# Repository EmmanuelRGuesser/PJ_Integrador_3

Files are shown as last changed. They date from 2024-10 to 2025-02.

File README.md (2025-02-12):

---
CI

# Medidor de consumo elétrico residencial com ESP32
---

Este projeto tem como objetivo realizar o projeto e implementação de um dispositivo de monitoramento do consumo energético de tomadas residenciais integrado ao Home Assistant.

Dispositivos como esse permitem aos usuários monitorar e controlar o consumo de energia, ajudando a identificar aparelhos que consomem muita energia e incentivar hábitos mais sustentáveis. Isso resulta em uma redução significativa na fatura de energia e contribui para a conservação de recursos naturais.

Com o aumento das tarifas de energia elétrica, ser capaz de identificar os maiores consumidores de energia em casa pode gerar economia substancial. Um dispositivo que fornece dados detalhados permite aos consumidores tomar decisões informadas para reduzir o consumo e, consequentemente, os custos.

## Funcionalidades:

- Integração com o Home Assistant;
- Monitoramento da tensão, corrente, potência, frequência e fator de potência;
- Visualiazação do histórico de consumo;
- Sistema de acionamento a distância;
- Sistema de proteção do dispositivo.  

## Dispositivo

O dispositivo funcionará entre as tomadas adquirindo os dados por meio do sensor PZEM-004T, abaixo temos uma representação dele:

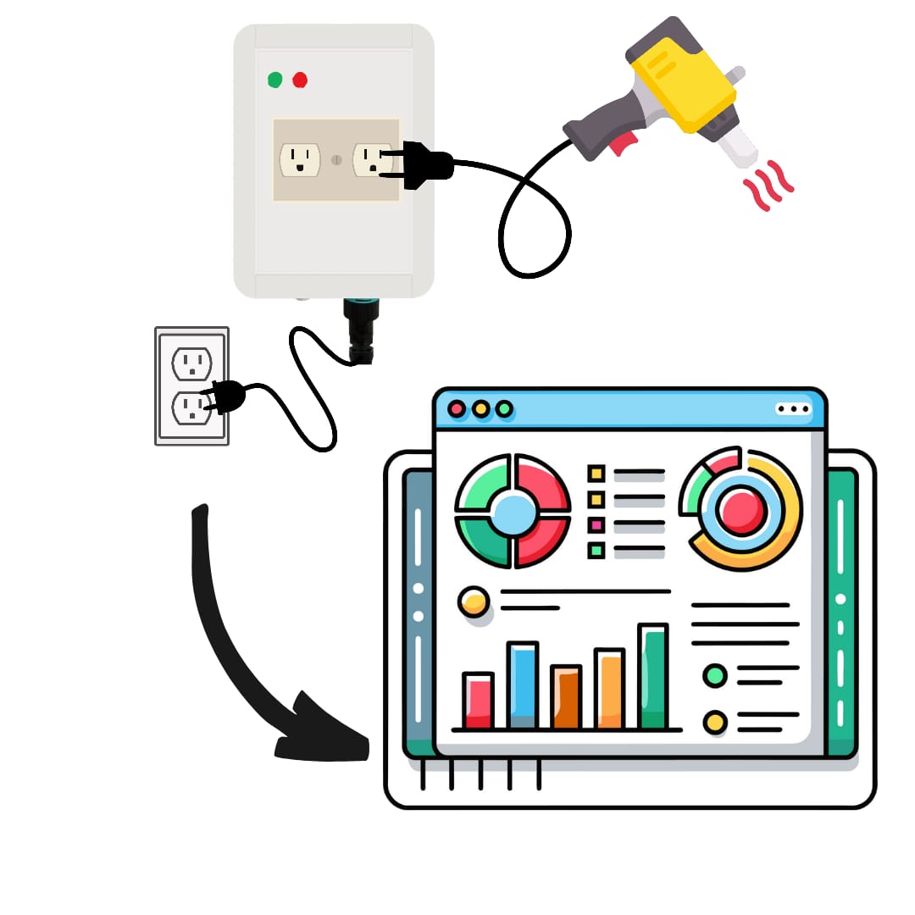
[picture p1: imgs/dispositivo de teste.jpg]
dispositivo


Ele deve ser conectado a tomada para o fornecimento de energia, dentro da case possui uma fonte para alimentar o ciruito. Esse circuito é composto pelo microcontrolador(ESP32), sensor(PZEM-004t), relé de acionamento e leds para fácil identificação do funcionamento, já a interface será integrada com o Home Assistant.

Para o projeto será utilizado os seguintes componentes:
- ESP32
- PZEM-004t
- Relé
- Fonte Hi-link 5V 3W
- 2 leds
- Display LCD 20x4
- Case takachi WPL15-15-6

---
## Descrição dos componentes

### ESP32
O ESP32 é um microcontrolador de baixo custo e baixa potência, desenvolvido pela Espressif Systems. Ele integra Wi-Fi e Bluetooth, tornando-se uma escolha popular para projetos de Internet das Coisas (IoT), além disso a comunidade em torno do ESP32 é enorme, com muitos recursos, bibliotecas e tutoriais disponíveis. A Espressif, empresa desenvolvedora, também oferece um SDK robusto (ESP-IDF). 

### PZEM-004t
O PZEM-004T é um módulo que possui funcionalidades de Voltimetro, Amperímetro e Wattimetro. Os dados são transmitidos para o microcontrolador por meio de comunicação serial TTL. 

### Fonte Hi-link 5V
É um conversor step down que trabalha com uma tensão de alimentação AC-DC 127/220V para 5V, com uma potencia de 5W, o qual será suficiente para alimentar o microcontrolador e os periféricos contidos no circuito. Foi escolhido esse modelo de fonte pois é compacta, facil de encontrar no mercado e possui certificações que garantem a qualidade da tensão e corrente entregues na saída, dentro da potencia especificada.

### LEDs
O dispositivo conta com dois leds que dão um feedback do funcionamento do sistema. Um led vermelho indicará que o circuito está ligado e outro led verde indicará estado de conexão com o wifi.

---
## Home Assistant

O Home Assistant é uma plataforma de automação residencial de código aberto que permite controlar dispositivos e sistemas em sua casa de maneira centralizada e automatizada. Ele suporta uma ampla variedade de dispositivos e protocolos, facilitando a criação de cenários de automação e controle de tudo, desde luzes e termostatos até câmeras de segurança e sistemas de entretenimento.

#### Principais características do Home Assistant:
- Automação: Criação de regras de automação personalizadas com base em eventos, horários ou condições específicas.
- Integrações: Suporte a milhares de dispositivos e serviços, como Philips Hue, Google Assistant, Amazon Alexa, entre muitos outros.
- Controle Local: Embora possa ser integrado à nuvem, o Home Assistant é projetado para funcionar localmente, o que oferece maior privacidade e controle.
- Dashboard Personalizado: A plataforma oferece uma interface visual personalizável para que você possa monitorar e controlar dispositivos.

#### Integração com ESP32 no Home Assistant
O ESP32 é um microcontrolador com conectividade Wi-Fi e Bluetooth, amplamente utilizado em projetos de automação e IoT (Internet das Coisas). No contexto do Home Assistant, o ESP32 é frequentemente usado para criar dispositivos personalizados, como sensores e atuadores. A integração entre o ESP32 e o Home Assistant ocorre principalmente por meio do protocolo MQTT Moskitto.

Funcionamento da Integração:

1. Configurar a rede Wi-Fi e login do Home Assistant na pagina WEB gerada pelo ESP.
2. O Home Assistant recebe os dados por meio do protocolo MQTT Moskito.
3. Armazena os dados em forma de entidades, no bando de dados InfluxDB.
4. No banco de dados possui um dashboard o qual mostra todos os dados plotados para o gerenciamento.

---

## Funcionamento do Monitor de Energia

Para o funcionamento do dispositivo devemos conectar a rede Wi-FI, isso é feito através do aplicativo ESP BLE Provising que está disponível na Play Store e App Store, leia o [código QR do link](https://espressif.github.io/esp-jumpstart/qrcode.html?data=%7B%22ver%22:%22v1%22,%22name%22:%22Monitor%20de%20energia%22,%22pop%22:%22abcd1234%22,%22transport%22:%22ble%22%7D) ou procure por monitor de energia e use a senha “abc1234”, com isso você pode ver as redes disponíveis e fazer a conexão, caso necessário reconfigurar a rede, somente pressione o botão ao lado da entrada de alimentação por 3 segundos que seu dispositivo irá reiniciar e basta seguir os passos anteriores. 

Agora é possível acessar a página de configurações através do Web Server gerado pela ESP32, acesse [monitor-energia.local](http://monitor-energia.local/), através dela você deve configurar o serviço MQTT para realizar a comunicação de dados entre o monitor de energia e o Home Assistant, use sua conta e senha do seu perfil do HA. Você também pode configurar os alertas, visualizar o consumo acumulado, além de ligar e desligar o dispositivo conectado através da página.

O sistema de alertas funciona como uma proteção que irá atuar desligando o dispositivo conectado ao monitor, a proteção age sobre tensão mínima e tensão, corrente e potência máxima, sempre que um alerta é disparado um aviso é exibido na tela, para voltar ao funcionamento basta clicar no botão ligar. Caso você queira não utilizar os alertas, somente deixe o item com 0. 
Na página de consumo acumulado é exibido quantidade de energia consumida pelo dispositivo conectado, com isso você pode estimar o valor gasto com ele, caso você queira trocar o dispositivo monitorado ou no que for necessário, você pode zerar o contador clicando em zerar energia.

Com isso, já é possível ver na tela LCD do monitor dados como tensão, corrente, potência e energia consumida, além dos avisos do dispositivos e informaçãoes já descritas acima, isso sem a necessidade de integrar com o Home Assistant , porém para conseguir monitorar os dados ao decorrer do tempo em um gráfico, você deve seguir os passos abaixo.

---
### Instalação do Home Assistant
Como o Home Assistant funciona localmente é necessário fazer a instalação em um computador, máquina virtual ou um Raspberry Pi por exemplo. 

Para acessar o processo de instalação [click aqui](https://www.home-assistant.io/installation/).

Com o Home Assistant instalado vamos adicionar o Moskitto MQTT

---
### Guia para Adicionar MQTT Mosquitto no Home Assistant
Instalar o Add-on:

Acesse Configurações → Add-ons, Backup & Supervisor
Vá em Loja de Add-ons e instale o Mosquitto broker
Configurar o Mosquitto:

No add-on, clique em Configuração e edite conforme necessário
Se precisar de autenticação, crie usuários em Configurações → Pessoas e Acesso
Habilitar e Iniciar:

Ative Iniciar na inicialização e Assistente de Rede
Clique em Iniciar
Verificar Funcionamento:

Vá em Configurações → Dispositivos e Serviços
Adicione uma integração MQTT, com isso no menu de configurações já deve ser possível se inscrever em algum tópico para receber os pacotes via MQTT.
No momento têm-se o tópico *sensor* e os sub tópicos *voltage, current, power, energy, frequency e pf*, para ver a tensão por exemplo, deve-se se inscrever no *sensor/voltage*, como resultado você deve ver algumo semelhante a isto:

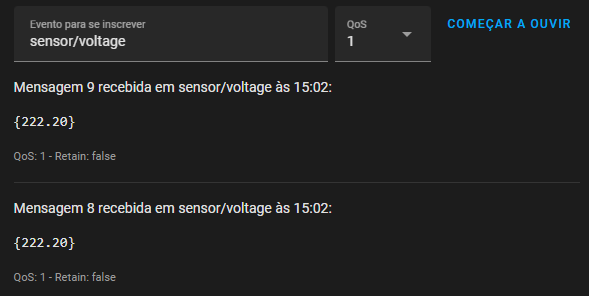
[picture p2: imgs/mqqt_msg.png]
mqtt_msg
 

Para salvar os dados será utilizado o File editor para criar as entidades que serão atribuidas aos dados que são recebidos via mqtt.

Com o File Editor aditaremos o arquivo */homeassistant/configuration.yaml*, basta adicionar o seguinte código para criar as entidades:
```
mqtt:    
    sensor:
        - name: voltage
          state_topic: "sensor/voltage"
          unit_of_measurement: V

        - name: current
          state_topic: "sensor/current"
          unit_of_measurement: A

        - name: power
          state_topic: "sensor/power"
          unit_of_measurement: W

        - name: energy
          state_topic: "sensor/energy"
          unit_of_measurement: Wh

        - name: frequency
          state_topic: "sensor/frequency"
          unit_of_measurement: Hz
          
        - name: fp
          state_topic: "sensor/pf"
          unit_of_measurement: fp
```
Agora vamos criar o banco de dados com o InfluxDB, para armazenar os dados e os manipular.

---
### Adicionando o InfluxDB no Home Assistant
Instalar o Add-on:

Acesse Configurações → Add-ons, Backup & Supervisor
Instale o InfluxDB
Criar um Banco de Dados e Usuário:

No terminal do InfluxDB, execute:
```
CREATE DATABASE home_assistant;
CREATE USER ha_user WITH PASSWORD 'senha' WITH ALL PRIVILEGES;
```
(Opcional) Restringir permissões:
```
GRANT ALL ON home_assistant TO ha_user;
```
Configurar no Home Assistant:
Adicione no configuration.yaml:
```
influxdb:
  host: a0d7b954-influxdb
  port: 8086
  database: home_assistant
  username: ha_user
  password: senha
  max_retries: 3
  default_measurement: state
```
Reinicie o Home Assistant

Para Verificar Funcionamento:

Acesse Desenvolvedor → Ferramentas de Estado para ver os dados sendo enviados

Pronto! Agora o MQTT e o InfluxDB estão integrados ao Home Assistant. 🚀

---
### Gerar o Dashboard e os gráficos no InfluxDB
1. Acessar o InfluxDB
2. No Home Assistant, vá para Configurações → Add-ons, Backup & Supervisor
Abra o InfluxDB e clique em Abrir Web UI
3. Criar um Dashboard
No menu lateral, vá em Dashboards
Clique em + Create Dashboard
Dê um nome ao dashboard e clique em Create
4. Criar um Gráfico
No dashboard criado, clique em + Create Cell
Escolha o tipo de visualização (Linha, Barras, Gauge, etc.)
Selecione Configure Query e escolha o banco de dados home_assistant
5. Construir a Query
   
OBS: O código das query estão no arquivo [Código_dos_gráficos_influxDB.md](https://github.com/EmmanuelRGuesser/PJ_Integrador_3/blob/main/C%C3%B3digo_dos_gr%C3%A1ficos_influxDB.md)

6. Utilizando os códigos, você pode personalizar os gráficos como desejar.

---

### Teste do Monitor de Energia

Para o teste vamos monitorar o carregamento de um notebook, após realizar as configuração de conexão do monitor e do Home Assistant conforme o passo a passo acima, podemos monitorar o consumo através da tela LCD no monitor ou pelo dashboard no Home Assistant.

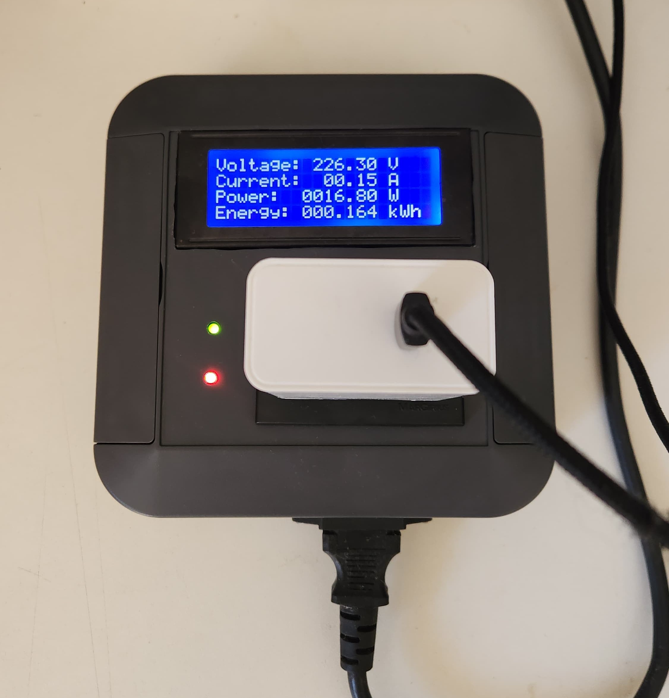
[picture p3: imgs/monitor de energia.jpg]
monitor
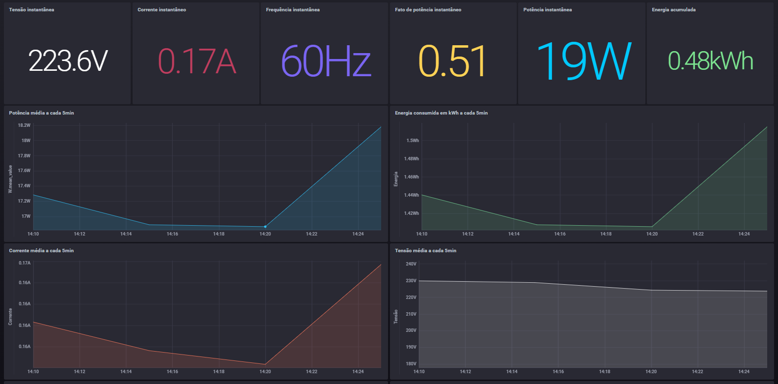
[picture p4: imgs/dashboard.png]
dashboard
  

Como visto acima podemos monitorar os parâmetros elétricos do dispositivo conectado ao monitor. Vamos testar o sistema de proteção, como a potência consumida é entre 15W - 20 W então para provocar um alerta iremos limitar em 10W, para isso entramos no página web do monitor de energia → configurar alertas e colocamos Max Power com 10W.

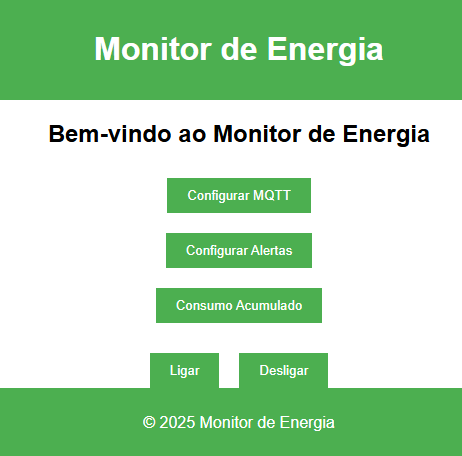
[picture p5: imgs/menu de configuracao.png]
tela principal
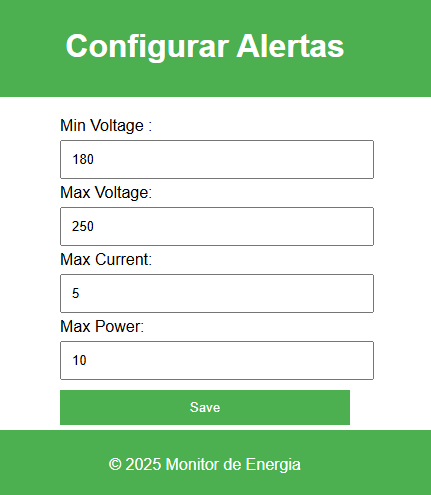
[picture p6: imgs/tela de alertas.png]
tela de alertas
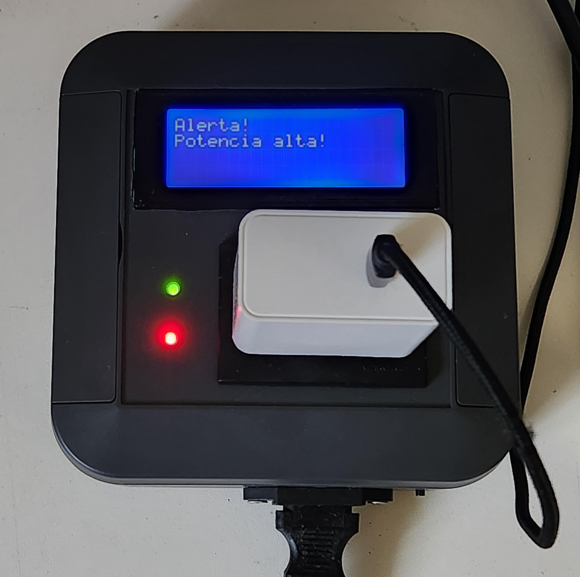
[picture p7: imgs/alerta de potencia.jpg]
alerta de potencia
  

Como vemos acima o monitor entra em modo proteção e desliga a carga, para voltar a funcionar é necessário ligar novamente no menu principal.

O consumo acumulado pode ser acessado pelo menu e la você poderá estimar o valor gasto pela caraga conectada, somente digite o valor pago por kWh e calcule. Caso você quiser zerar o contador nesta página também é possível fazer isto.

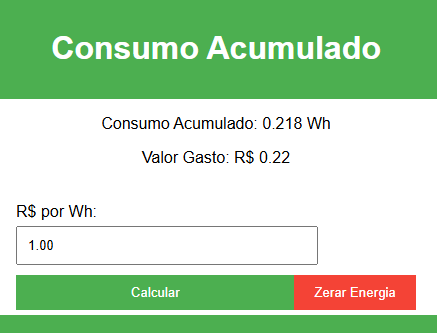
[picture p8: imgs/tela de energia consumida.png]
tela energia consumida


---

## Considerações finais

O desenvolvimento do projeto atingiu seus objetivos propostos, resultando em um dispositivo funcional capaz de monitorar o consumo elétrico de forma eficiente. A integração do hardware e software permitiu a coleta e visualização dos dados em tempo real, proporcionando um produto prático para automação residencial. Para projetos futuros, considera-se a possibilidade de utilizar um banco de dados mais robusto, um software mais avançado para a criação do dashboard e a adoção de componentes SMD para um design mais compacto, eficiente e profissional, reduzindo o tamanho da case e aprimorando a estética e usabilidade do dispositivo.

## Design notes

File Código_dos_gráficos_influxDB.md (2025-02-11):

---
#### Este arquivo contem os códigos referente aos gráficos gerados no dashboard dentro do InfluxDB.
## Valores instantâneos:

#### Tensão:
```
SELECT last("value") AS "instant_voltage"
FROM "sensor"."autogen"."V"
WHERE time > :dashboardTime: AND time < :upperDashboardTime:
```
#### Corrente:
```
SELECT last("value") AS "instant_value"
FROM "sensor"."autogen"."A"
WHERE time > :dashboardTime: AND time < :upperDashboardTime:
```
#### Frequencia:
```
SELECT last("value") AS "frequencia"
FROM "sensor"."autogen"."Hz"
WHERE time > :dashboardTime: AND time < :upperDashboardTime:
```
#### Fator de potencia:
```
SELECT last("value") AS "fatordepotencia"
FROM "sensor"."autogen"."fp"
WHERE time > :dashboardTime: AND time < :upperDashboardTime:
```
#### Potencia:
```
SELECT last("value") AS "instant_power"
FROM "sensor"."autogen"."W"
WHERE time > :dashboardTime: AND time < :upperDashboardTime:
```
#### Energia:
```
SELECT last("value") AS "instant_energy"
FROM "sensor"."autogen"."Wh"
WHERE time > :dashboardTime: AND time < :upperDashboardTime:
```
## Valores média de 5min:

#### Tensão média:
```
SELECT mean("value") AS "mean_voltage"
FROM "sensor"."autogen"."V"
WHERE time > :dashboardTime: AND time < :upperDashboardTime:
GROUP BY time(5m) FILL(null)
```
#### Corrente média:
```
SELECT mean("value") AS "Corrente média"
FROM "sensor"."autogen"."A"
WHERE time > :dashboardTime: AND time < :upperDashboardTime:
GROUP BY time(5m) FILL(null)
```
#### Frequencia média:
```
SELECT mean("value") AS "Frequencia"
FROM "sensor"."autogen"."Hz"
WHERE time > :dashboardTime: AND time < :upperDashboardTime:
GROUP BY time(5m) FILL(null)
```
#### Fator de potencia média:
```
SELECT mean("value") AS "PF"
FROM "sensor"."autogen"."fp"
WHERE time > :dashboardTime: AND time < :upperDashboardTime:
GROUP BY time(5m) 
FILL(null)

```
#### Potencia média:
```
SELECT mean("value") AS "mean_value"
FROM "sensor"."autogen"."W"
WHERE time > :dashboardTime: AND time < :upperDashboardTime:
GROUP BY time(5m) FILL(null)
```
#### Energia média:
```
SELECT mean("value") * (5/60) AS "energy_Wh" 
FROM "sensor"."autogen"."W" 
WHERE time > :dashboardTime: AND time < :upperDashboardTime: 
GROUP BY time(5m) FILL(null)
```
## Valor total por dia da última semana:

#### Potencia total do dia na ultima semana:
```
SELECT sum("value") AS "Potencia total"
FROM "sensor"."autogen"."W"
WHERE time >= now() - 7d AND time < now()
GROUP BY time(1d) FILL(null)
```
#### Energia tota do dia na ultima semana:
```
SELECT sum(energy_Wh) AS "daily_energy_Wh" 
FROM (
    SELECT mean("value") * (5/60) AS energy_Wh 
    FROM "sensor"."autogen"."W" 
    WHERE time > now() - 7d 
    GROUP BY time(5m) 
    FILL(null)
) 
GROUP BY time(1d) 
FILL(null)
```

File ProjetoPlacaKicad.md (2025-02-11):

---
#### Projeto da placa
---

Foi utilizado o Kicad 8.0 para realizar o projeto do esquemático e layout da placa, o modelo 3D tambem.

Na imagem abaixo, verifica-se o esquemático, contendo as ligações da alimentação utilizando uma fonte Hi-link 5V e 5W, circuito para reset da carga utilizando um acionamento de relé, sensor PZEN-004T com comunicação serial, os leds indicativos de alimentação e conexão com WiFi e o display LCD que utiliza o protocolo I2C.
CI

Na imagem abaixo podemos verificar o layout da placa, foi utilizado uma PCI de única face com dimensões de 10x8cm
CI

Na imagem abaixo podemos verificar o modelo 3D.
CI

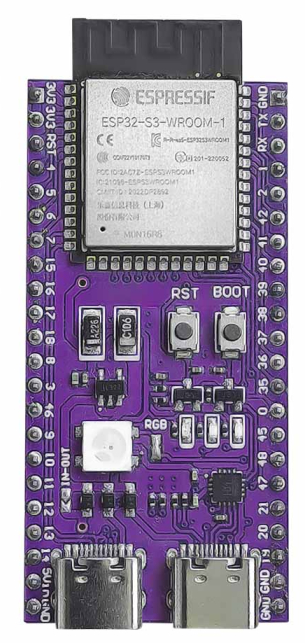
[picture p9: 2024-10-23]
imgs/esp32.png

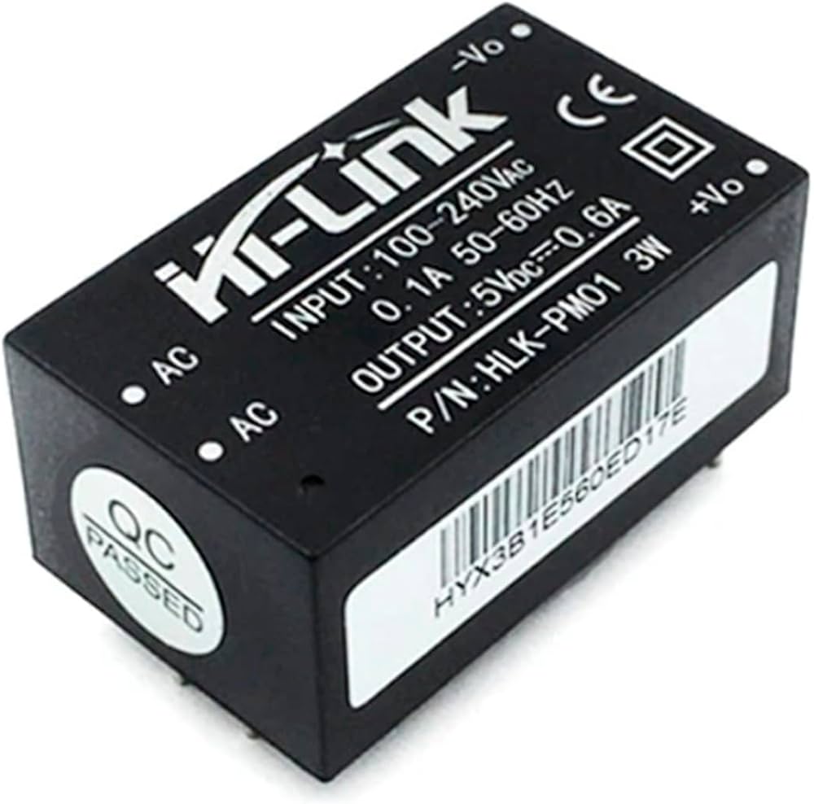
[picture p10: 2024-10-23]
imgs/fonte.jpg

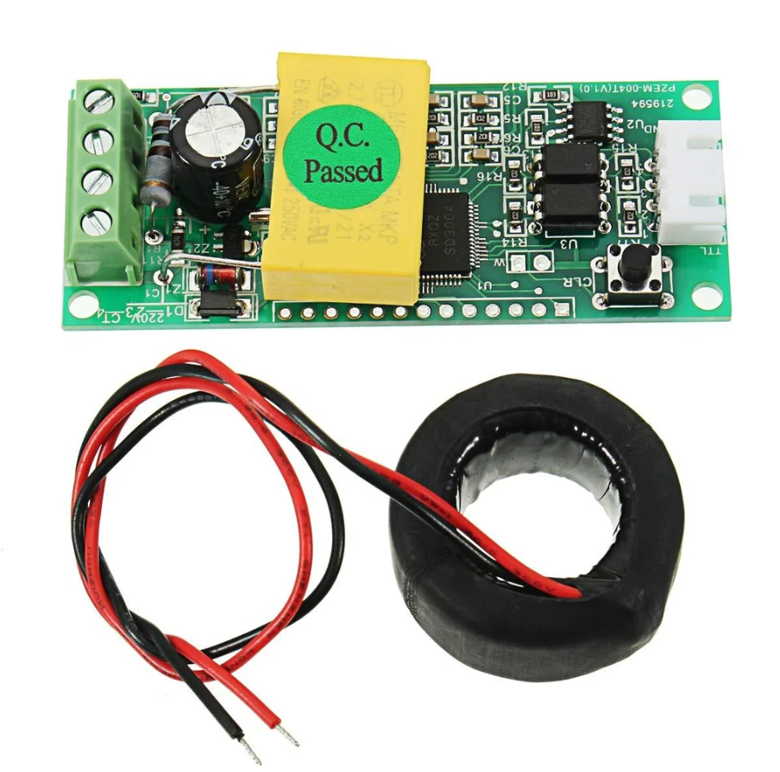
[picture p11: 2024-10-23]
imgs/pzem-004.png

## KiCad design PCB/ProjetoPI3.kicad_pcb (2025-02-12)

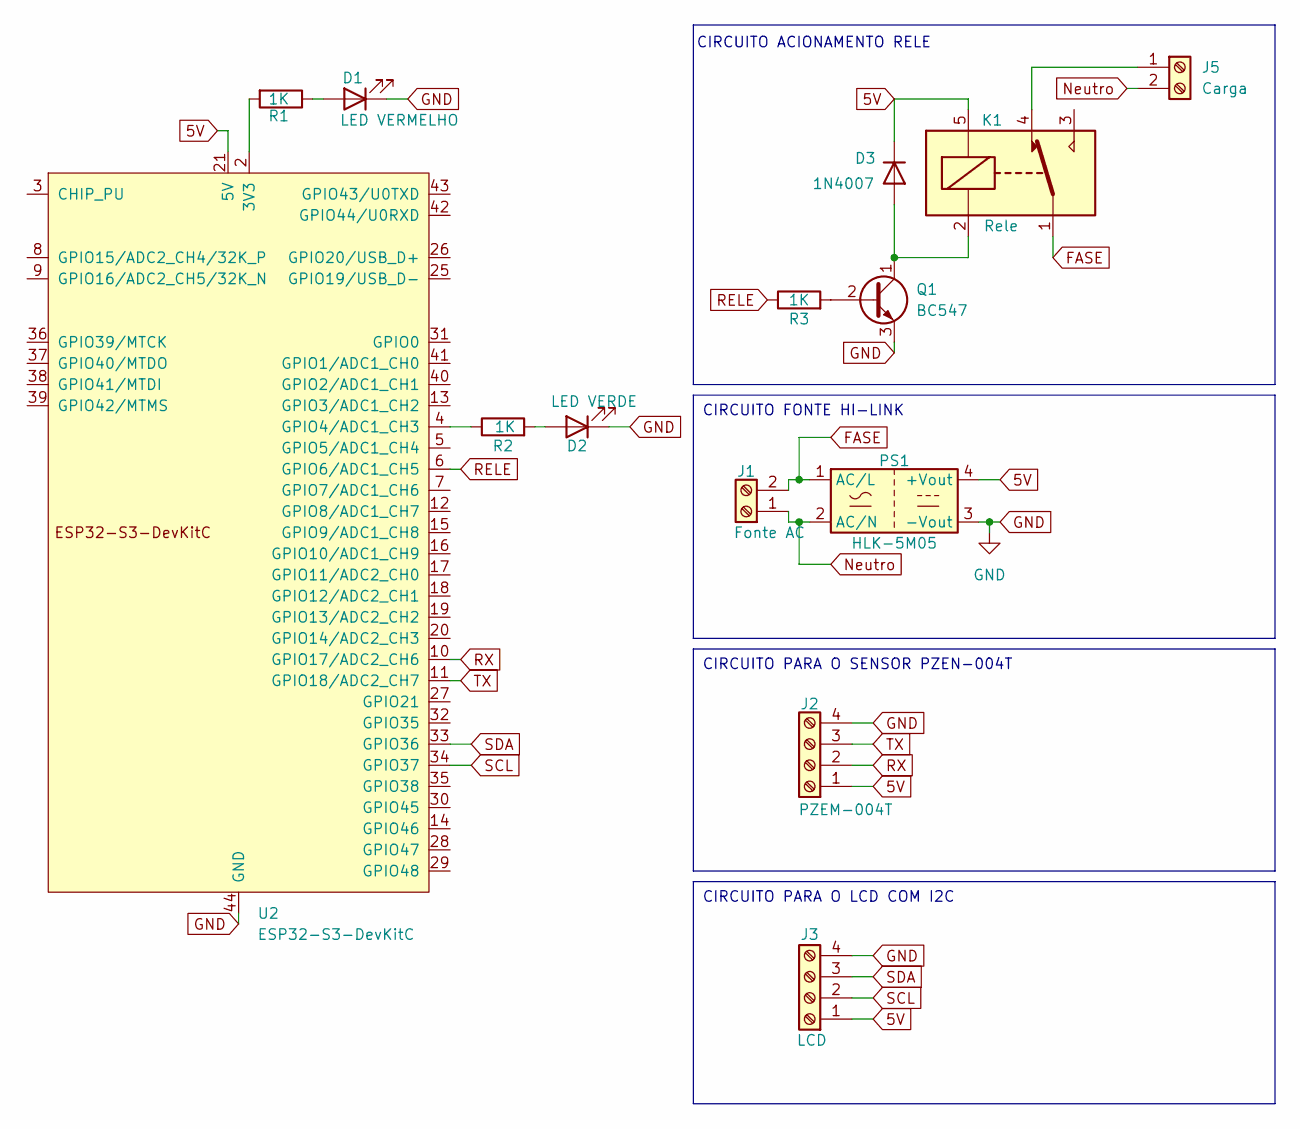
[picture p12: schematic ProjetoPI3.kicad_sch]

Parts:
D1: LED VERMELHO; TerminalBlock_Altech_AK300-2_P5.00mm
D2: LED VERDE; TerminalBlock_Altech_AK300-2_P5.00mm
D3: 1N4007; D_DO-41_SOD81_P10.16mm_Horizontal
J1: Fonte AC; TerminalBlock_Altech_AK300-2_P5.00mm
J2: PZEM-004T; TerminalBlock_Altech_AK300-4_P5.00mm
J3: LCD; TerminalBlock_Altech_AK300-4_P5.00mm
J5: Carga; TerminalBlock_Altech_AK300-2_P5.00mm
K1: Rele; Relay_SPDT_SANYOU_SRD_Series_Form_C
PS1: HLK-5M05; Converter_ACDC_Hi-Link_HLK-5Mxx
Q1: BC547; TO-92_Inline
R1, R2, R3: 1K; R_Axial_DIN0207_L6.3mm_D2.5mm_P10.16mm_Horizontal
U2: ESP32-S3-DevKitC

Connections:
5V: D3.1 (K), J2.1, J3.1, K1.5, PS1.4 (+Vout), U2.21 (5V)
FASE: J1.2, K1.1, PS1.1 (AC/L)
GND: D1.1 (K), D2.1 (K), J2.4, J3.4, PS1.3 (-Vout), Q1.3 (E), U2.22 (GND), U2.23 (GND), U2.24 (GND), U2.44 (GND)
unnamed: D1.2 (A), R1.1
unnamed: D2.2 (A), R2.2
unnamed: D3.2 (A), K1.2, Q1.1 (C)
unnamed: J5.1, K1.4
unnamed: Q1.2 (B), R3.2
unnamed: R1.2, U2.1 (3V3), U2.2 (3V3)
unnamed: R2.1, U2.4 (GPIO4/ADC1_CH3)
Neutro: J1.1, J5.2, PS1.2 (AC/N)
RELE: R3.1, U2.6 (GPIO6/ADC1_CH5)
RX: J2.2, U2.10 (GPIO17/ADC2_CH6)
SCL: J3.2, U2.34 (GPIO37)
SDA: J3.3, U2.33 (GPIO36)
TX: J2.3, U2.11 (GPIO18/ADC2_CH7)

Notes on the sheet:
CIRCUITO PARA O SENSOR PZEN-004T
CIRCUITO FONTE HI-LINK
CIRCUITO PARA O LCD COM I2C
CIRCUITO ACIONAMENTO RELE

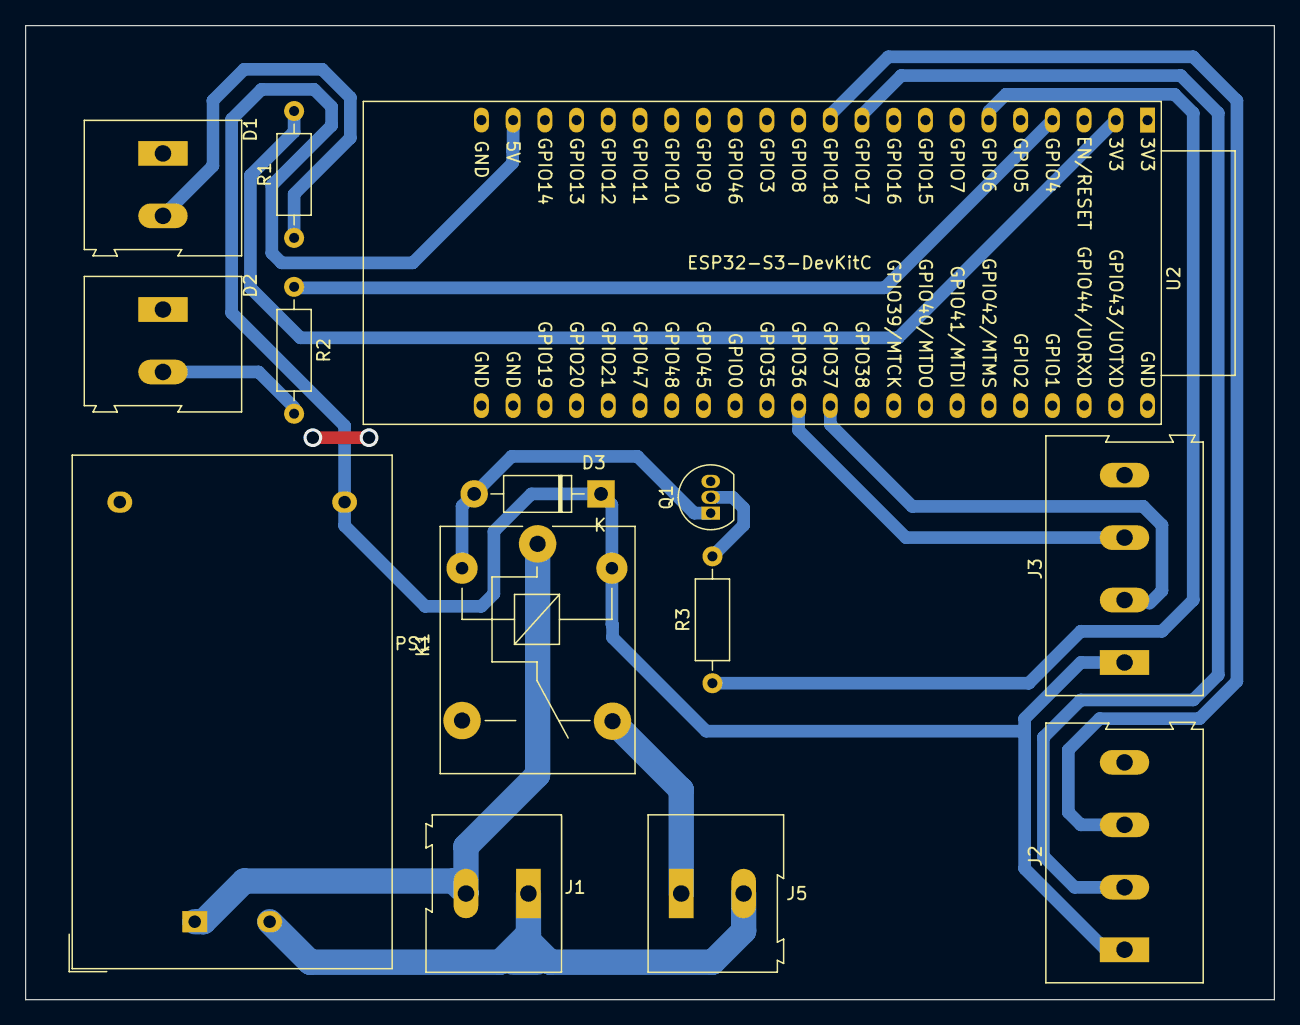
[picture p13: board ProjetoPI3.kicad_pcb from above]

Board: 2 copper layers, 100.0 x 78.0 mm, 14 parts (0 on the bottom side), 16 nets.

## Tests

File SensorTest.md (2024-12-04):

# Atualizações do andamento do projeto

- [x] Conexão WIFI
- [x] Conexão MQTT com o Home Assistant
- [x] Leitura de tensão, corrente, potência e outros
- [x] Banco de dados
- [ ] Dashboard
- [ ] Alarmes e sistema de proteção
- [ ] Busca automática do broker ip

## Manual de utilização

No arquivo *config.h* você deve colocar os dados da rede wifi, o usuário e senha da sua conta do home assistant e URI do broker MQTT.

Já com o Home Assistant instalado, baixe o Mosquitto Broker na loja de add-ons e adicione no menu de integrações, com isso no menu de configurações já deve ser possível se inscrever em algum tópico para receber os pacotes via MQTT.
No momento têm-se o tópico *sensor* e os sub tópicos *voltage, current, power, energy, frequency e pf*, para ver a tensão por exemplo, deve-se se inscrever no *sensor/voltage*, como resultado você deve ver algumo semelhante a isto:

mqtt_msg

Para o teste foram feita as conexões seguindo o datasheet do PZEM-004T:

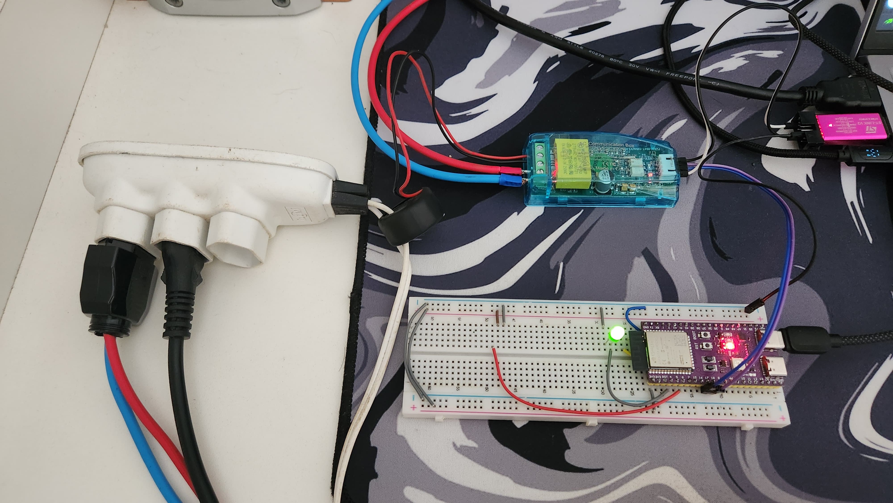
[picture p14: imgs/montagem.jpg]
teste


Para salvar os dados será utilizado o File editor para criar as entidades que serão atribuidas aos dados que são recebidos via mqtt e o InfluxDB que será nosso banco de dados, para isso você deve instalá-los na loja de add-ons. 

Com o File Editor aditaremos o arquivo */homeassistant/configuration.yaml*, basta adicionar o seguinte código para criar as entidades:
```
mqtt:    
    sensor:
        - name: voltage
          state_topic: "sensor/voltage"
          unit_of_measurement: V

        - name: current
          state_topic: "sensor/current"
          unit_of_measurement: A

        - name: power
          state_topic: "sensor/power"
          unit_of_measurement: W

        - name: energy
          state_topic: "sensor/energy"
          unit_of_measurement: Wh
```

Já no InfluxDB para criar um database você de ir em *InfluxDB Admin -> Database -> Create Database* nomeie ele e está feito. Ainda na mesma seção, crie um usuário e de permissão para leitura e escrita no database criado anteriormente.

Agora no novamente com o File Editor edite o novamente o arquivo */homeassistant/configuration.yaml* adicianando as informações de database e user criados, por exemplo:
```
influxdb:
    database: sensor
    username: admin
    password: admin123
```

Caso você queira visualizar os dados, você pode criar um dashboard em *Dashboard -> Create Dashboard*. Após criar uma célula, nomeie o gráfico, selecione o banco de dados e a informação desejada, por exemplo a corrente é 
 "A", após isso confimre.

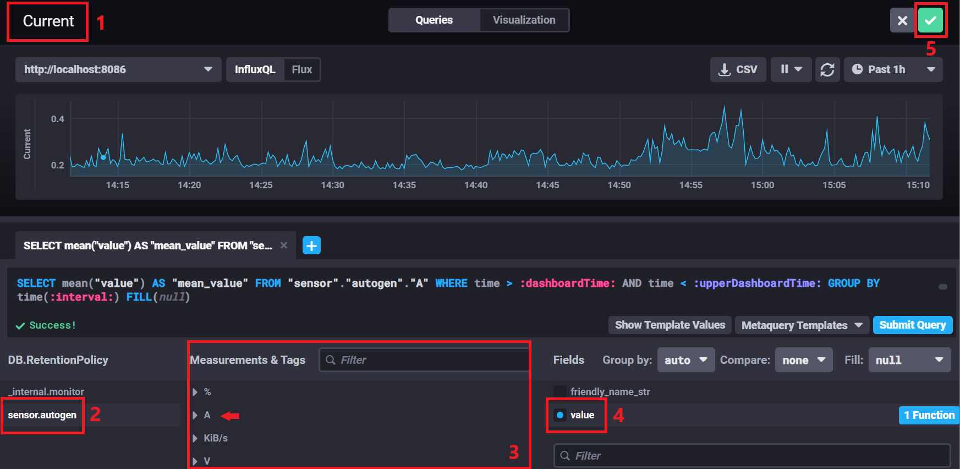
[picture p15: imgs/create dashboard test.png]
dashboard1


Criando outros gráficos voce terá um resultado semelhante a este:

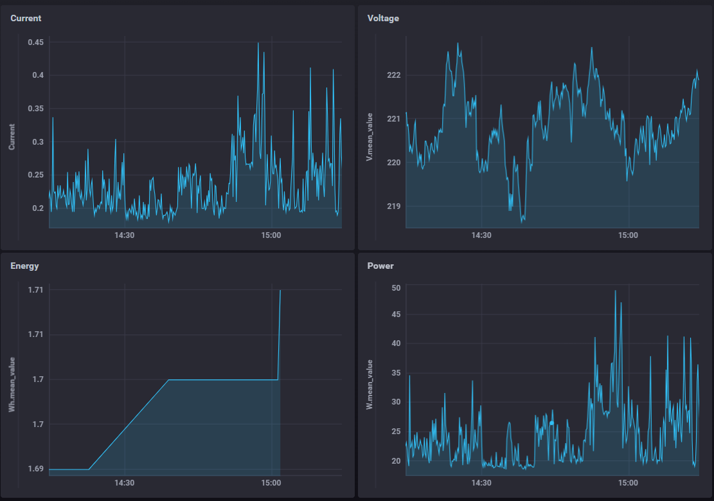
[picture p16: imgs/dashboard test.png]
dashboard2


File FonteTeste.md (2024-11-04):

---
#### Teste realizado com a fonte Hi-Link
---

Para iniciar o teste foi feito a solda da fonte em uma placa perfurada com dois bornes para encaixe da alimentação e do resitor de saída.
CI

Após finalizar a montagem da placa de teste, foi realizado teste com o multímetro, afim de verificar a tensão de saída.
CI

E tambem teste no osciloscópio, conforme a imagem abaixo
F0000TEK

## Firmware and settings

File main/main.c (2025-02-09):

#include <stdio.h>
#include <stdint.h>
#include <string.h>
#include "freertos/FreeRTOS.h"
#include "freertos/task.h"
#include "mqtt_client.h"
#include <nvs_flash.h>

#include "pzem004tv3.h"
#include "hd44780.h"
#include "pcf8574.h"
#include "wifi_connect.h"
#include "web_server.h"
#include "esp_spiffs.h"

/* @brief Set ESP32  Serial Configuration */
pzem_setup_t pzConf =
{
    .pzem_uart   = UART_NUM_1,              /*  <== Specify the UART you want to use, UART_NUM_0, UART_NUM_1, UART_NUM_2 (ESP32 specific) */
    .pzem_rx_pin = GPIO_NUM_18,             /*  <== GPIO for RX */
    .pzem_tx_pin = GPIO_NUM_17,             /*  <== GPIO for TX */
    .pzem_addr   = PZ_DEFAULT_ADDRESS,      /*  If your module has a different address, specify here or update the variable in pzem004tv3.h */
};

TaskHandle_t PMonTHandle = NULL;
TaskHandle_t LcdHandle = NULL;
TaskHandle_t AlertHandle = NULL;
_current_values_t pzValues;
bool relay_flag = false;
float voltage_min = 0.0;
float voltage_max = 0.0;
float current_max = 0.0;
float power_max = 0.0;
static i2c_dev_t pcf8574;

static esp_err_t write_lcd_data(const hd44780_t *lcd, uint8_t data)
{
    return pcf8574_port_write(&pcf8574, data);
}

hd44780_t lcd = {
    .write_cb = write_lcd_data, // use callback to send data to LCD by I2C GPIO expander
    .font = HD44780_FONT_5X8,
    .lines = 4,
    .pins = {
        .rs = 0,
        .e  = 2,
        .d4 = 4,
        .d5 = 5,
        .d6 = 6,
        .d7 = 7,
        .bl = 3
    }
};

void PMonTask( void * pvParameters );
void lcdTask( void * pvParameters );

void alertTask( void * pvParameters );

void app_main()
{   
    /* Initialize NVS partition */
    esp_err_t ret = nvs_flash_init();
    if (ret == ESP_ERR_NVS_NO_FREE_PAGES || ret == ESP_ERR_NVS_NEW_VERSION_FOUND) {
        /* NVS partition was truncated
         * and needs to be erased */
        ESP_ERROR_CHECK(nvs_flash_erase());
        /* Retry nvs_flash_init */
        ESP_ERROR_CHECK(nvs_flash_init());
    }

    /* Initialize LCD */
    ESP_ERROR_CHECK(i2cdev_init());
    xTaskCreate( lcdTask, "LCD", (512 * 8), NULL, tskIDLE_PRIORITY + 1, &LcdHandle );
    load_credentials(); // Verifica se a credenciais HA salva
    xTaskCreate( PMonTask, "PowerMon", ( 512 * 8 ), NULL, tskIDLE_PRIORITY + 1, &PMonTHandle );
    xTaskCreate( alertTask, "AlertTask", ( 512 * 8 ), NULL, tskIDLE_PRIORITY + 1, &AlertHandle );
}

void PMonTask( void * pvParameters )
{
    PzemInit( &pzConf );
    PzResetEnergy( &pzConf );
    while(1)
    {        
        if (mqtt_client != NULL && PzemGetValues( &pzConf, &pzValues )) {
            printf( "Vrms: %.1fV - Irms: %.3fA - P: %.1fW - E: %.2fWh\n", pzValues.voltage, pzValues.current, pzValues.power, pzValues.energy );
            printf( "Freq: %.1fHz - PF: %.2f\n", pzValues.frequency, pzValues.pf );
            
            // Publish MQTT messages
            char message[24];
            snprintf(message, sizeof(message), "%.2f", pzValues.voltage);
            esp_mqtt_client_publish(mqtt_client, MQTT_TOPIC_VOLTAGE, message, 0, 1, 0);
            snprintf(message, sizeof(message), "%.2f", pzValues.current);
            esp_mqtt_client_publish(mqtt_client, MQTT_TOPIC_CURRENT, message, 0, 1, 0);
            snprintf(message, sizeof(message), "%.2f", pzValues.power);
            esp_mqtt_client_publish(mqtt_client, MQTT_TOPIC_POWER, message, 0, 1, 0);
            snprintf(message, sizeof(message), "%.2f", pzValues.energy);
            esp_mqtt_client_publish(mqtt_client, MQTT_TOPIC_ENERGY, message, 0, 1, 0);
            snprintf(message, sizeof(message), "%.2f", pzValues.frequency);
            esp_mqtt_client_publish(mqtt_client, MQTT_TOPIC_FREQUENCY, message, 0, 1, 0);
            snprintf(message, sizeof(message), "%.2f", pzValues.pf);
            esp_mqtt_client_publish(mqtt_client, MQTT_TOPIC_PF, message, 0, 1, 0);



            // Atualiza o LCD
            hd44780_gotoxy(&lcd, 0, 0);
            snprintf(message, sizeof(message), "Voltage: %6.2f V", pzValues.voltage);
            hd44780_puts(&lcd, message);

            hd44780_gotoxy(&lcd, 0, 1);
            snprintf(message, sizeof(message), "Current:  %05.2f A", pzValues.current);
            hd44780_puts(&lcd, message);

            hd44780_gotoxy(&lcd, 0, 2);
            snprintf(message, sizeof(message), "Power:  %07.2f W", pzValues.power);
            hd44780_puts(&lcd, message);

            hd44780_gotoxy(&lcd, 0, 3);
            snprintf(message, sizeof(message), "Energy: %07.3f kWh", pzValues.energy);
            hd44780_puts(&lcd, message);

            // Compara os valores dos alertas com os valores medidos
            if (voltage_min != 0.0 && pzValues.voltage < voltage_min){
                relay_flag = true;
                hd44780_clear(&lcd);
                hd44780_gotoxy(&lcd, 0, 0);
                hd44780_puts(&lcd, "Alerta!");
                hd44780_gotoxy(&lcd, 0, 1);
                hd44780_puts(&lcd, "Tensao baixa!");
                vTaskSuspend(PMonTHandle); // Suspende a tarefa PMonTask
            } else if (voltage_max != 0.0 && pzValues.voltage > voltage_max){
                relay_flag = true;
                hd44780_clear(&lcd);
                hd44780_gotoxy(&lcd, 0, 0);
                hd44780_puts(&lcd, "Alerta!");
                hd44780_gotoxy(&lcd, 0, 1);
                hd44780_puts(&lcd, "Tensao alta!");
                vTaskSuspend(PMonTHandle); // Suspende a tarefa PMonTask
            } else if (current_max != 0.0 && pzValues.current > current_max) {
                relay_flag = true;
                hd44780_clear(&lcd);
                hd44780_gotoxy(&lcd, 0, 0);
                hd44780_puts(&lcd, "Alerta!");
                hd44780_gotoxy(&lcd, 0, 1);
                hd44780_puts(&lcd, "Corrente alta!");
                vTaskSuspend(PMonTHandle); // Suspende a tarefa PMonTask
            } else if (power_max != 0.0 && pzValues.power > power_max) {
                relay_flag = true;
                hd44780_clear(&lcd);
                hd44780_gotoxy(&lcd, 0, 0);
                hd44780_puts(&lcd, "Alerta!");
                hd44780_gotoxy(&lcd, 0, 1);
                hd44780_puts(&lcd, "Potencia alta!");
                vTaskSuspend(PMonTHandle); // Suspende a tarefa PMonTask
            }
        }
        ESP_LOGI( TAG, "Stack High Water Mark: %ld Bytes free", ( unsigned long int ) uxTaskGetStackHighWaterMark( NULL ) );     /* Show's what's left of the specified stacksize */
        vTaskDelay(pdMS_TO_TICKS(1000));
    }
    vTaskDelete( NULL );
}

void lcdTask(void *pvParameters)
{
    memset(&pcf8574, 0, sizeof(i2c_dev_t));
    ESP_ERROR_CHECK(pcf8574_init_desc(&pcf8574, 0x3f, 0, 36, 37));
    ESP_ERROR_CHECK(hd44780_init(&lcd));
    hd44780_switch_backlight(&lcd, true);

    hd44780_gotoxy(&lcd, 0, 0);
    hd44780_puts(&lcd, "Projeto de PI3");
    hd44780_gotoxy(&lcd, 0, 2);
    hd44780_puts(&lcd, "Medidor de Energia");
    vTaskDelay(pdMS_TO_TICKS(3000));
    hd44780_clear(&lcd);
    wifi_init();
    start_webserver();
    
    vTaskDelete( NULL );
}

void alertTask(void *pvParameters) {

    gpio_config_t io_conf_rele = {
        .intr_type = GPIO_INTR_DISABLE,       // Sem interrupção
        .mode = GPIO_MODE_OUTPUT,             // Configura como saída
        .pin_bit_mask = (1ULL << GPIO_NUM_6), // Seleciona o pino
        .pull_down_en = GPIO_PULLDOWN_DISABLE,// Desabilita o pull-down
        .pull_up_en = GPIO_PULLUP_DISABLE,    // Desabilita o pull-up
    };
    gpio_config(&io_conf_rele);
    gpio_set_level(GPIO_NUM_6, 0);

    while (1) {
        // Ler os valores dos alertas da NVS
        nvs_handle_t nvs_handle;
        esp_err_t err = nvs_open("storage", NVS_READONLY, &nvs_handle);
        if (err == ESP_OK) {
            size_t required_size;
            nvs_get_str(nvs_handle, "voltage_min", NULL, &required_size);
            char* voltage_min_str = malloc(required_size);
            nvs_get_str(nvs_handle, "voltage_min", voltage_min_str, &required_size);
            voltage_min = atof(voltage_min_str);
            free(voltage_min_str);

            nvs_get_str(nvs_handle, "voltage_max", NULL, &required_size);
            char* voltage_max_str = malloc(required_size);
            nvs_get_str(nvs_handle, "voltage_max", voltage_max_str, &required_size);
            voltage_max = atof(voltage_max_str);
            free(voltage_max_str);

            nvs_get_str(nvs_handle, "current_max", NULL, &required_size);
            char* current_max_str = malloc(required_size);
            nvs_get_str(nvs_handle, "current_max", current_max_str, &required_size);
            current_max = atof(current_max_str);
            free(current_max_str);

            nvs_get_str(nvs_handle, "power_max", NULL, &required_size);
            char* power_max_str = malloc(required_size);
            nvs_get_str(nvs_handle, "power_max", power_max_str, &required_size);
            power_max = atof(power_max_str);
            free(power_max_str);

            nvs_close(nvs_handle);
        }

        if(relay_flag) {
            vTaskSuspend(PMonTHandle); // Suspende a tarefa PMonTask
            gpio_set_level(GPIO_NUM_6, 1); //Desliga

        } else {
            gpio_set_level(GPIO_NUM_6, 0); //Liga
            vTaskDelay(pdMS_TO_TICKS(5000));
            vTaskResume(PMonTHandle); // Retoma a tarefa PMonTask
        }       
        vTaskDelay(pdMS_TO_TICKS(1000));
    }
    vTaskDelete(NULL);
}

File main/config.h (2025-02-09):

// Configurações MQTT
#define MQTT_BROKER_URI      "mqtt://homeassistant.local"
#define MQTT_TOPIC_VOLTAGE   "sensor/voltage"
#define MQTT_TOPIC_CURRENT   "sensor/current"
#define MQTT_TOPIC_POWER     "sensor/power"
#define MQTT_TOPIC_ENERGY    "sensor/energy"
#define MQTT_TOPIC_FREQUENCY "sensor/frequency"
#define MQTT_TOPIC_PF        "sensor/pf"

// // Configurações do home assistant
// #define username_ha "projetopi"
// #define password_ha "#%BicUrS*ZmS5UF"

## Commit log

2024-10-23 Update README.md
    atualização na descrição da fonte hi-link e do sensor PZEM-004T
2024-11-04 Update and rename FonteTeste to FonteTeste.md
    Finalizado arquivo de testes fonte
2024-12-04 Add imagens de exemplo
2025-02-09 Atualizações e adição de funcionalidades.
    Adicionado WebServer, atualizações no provisionamento WiFi e MQTT e correções no display.
    [partitions.csv]
2025-02-12 Add PCB
    [ProjetoPI3.kicad_pcb, ProjetoPI3.kicad_sch]
